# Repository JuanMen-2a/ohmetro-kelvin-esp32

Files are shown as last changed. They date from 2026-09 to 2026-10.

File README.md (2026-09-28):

# Óhmetro Kelvin de 4 Hilos — ESP32 + MQTT + Android

> Trabajo Final — Diseño Electrónico, UIS 2026-II

Instrumento de medición de resistencias de bajo valor (rango: miliohmios) basado en el método Kelvin de 4 hilos. El ESP32 adquiere la señal, la procesa y la transmite vía MQTT a una app Android en tiempo real.

---

## Arquitectura del sistema
Circuito Kelvin → ESP32 → Hotspot celular → Internet → test.mosquitto.org → Internet → App Android

---

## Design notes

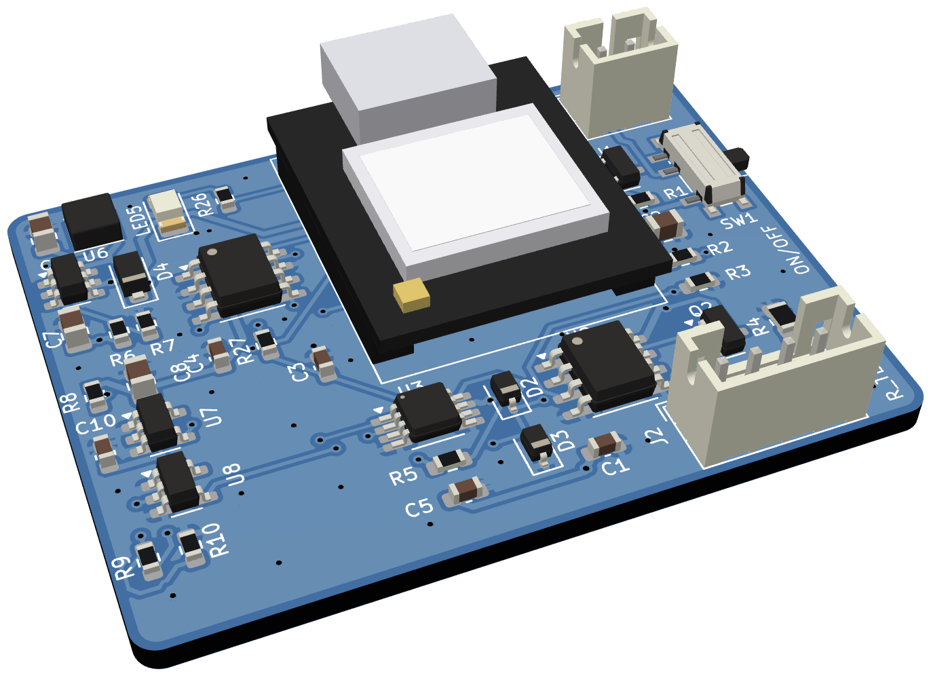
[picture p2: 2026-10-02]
PCB/imagenes/PCB_3D_isometrica.png

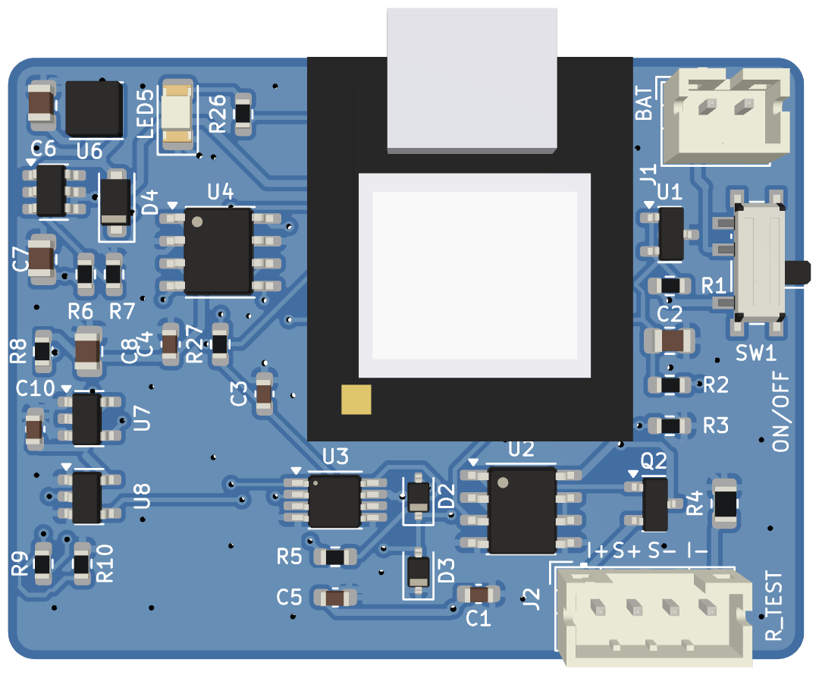
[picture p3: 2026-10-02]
PCB/imagenes/PCB_3D_superior.png

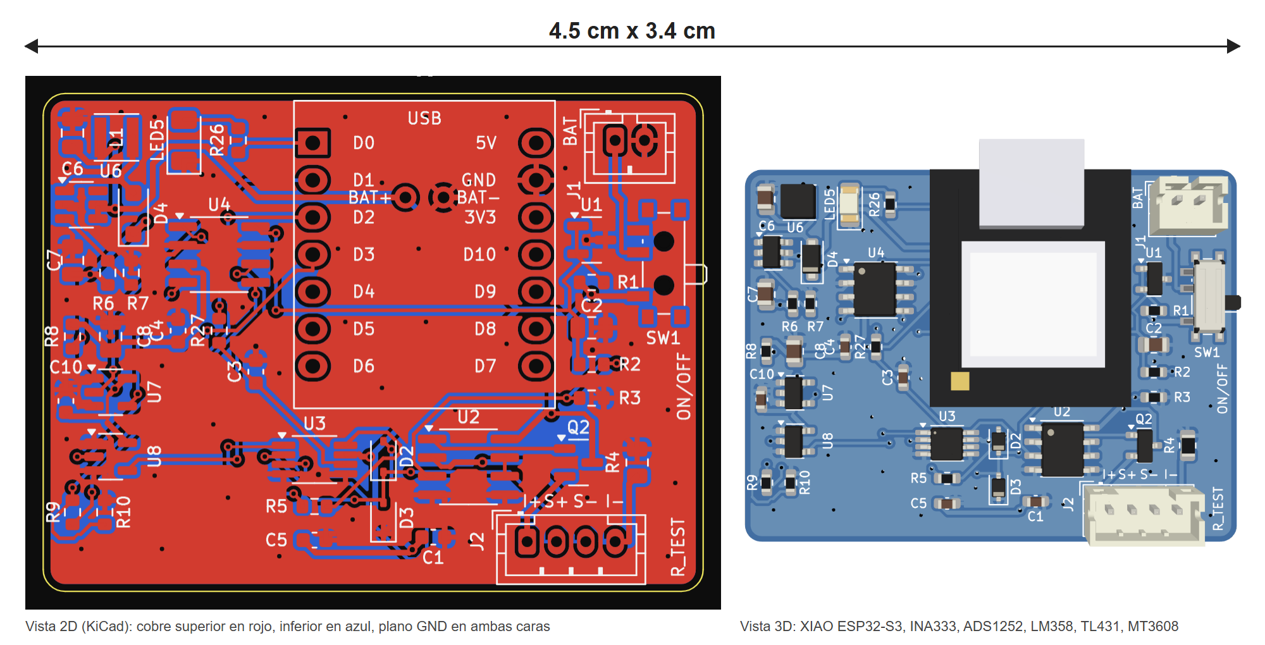
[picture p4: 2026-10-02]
PCB/imagenes/PCB_2D_3D.png

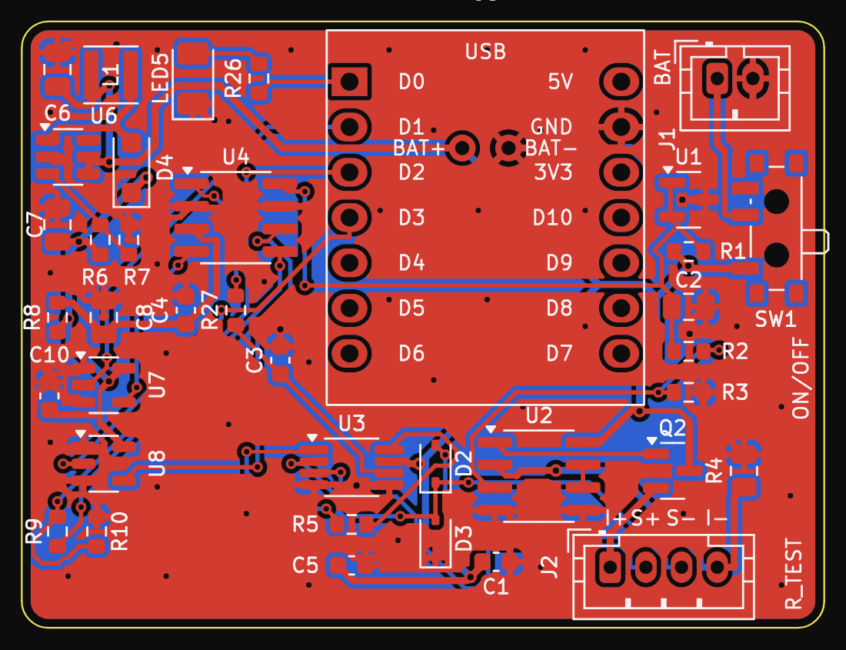
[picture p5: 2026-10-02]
PCB/imagenes/PCB_2D.png

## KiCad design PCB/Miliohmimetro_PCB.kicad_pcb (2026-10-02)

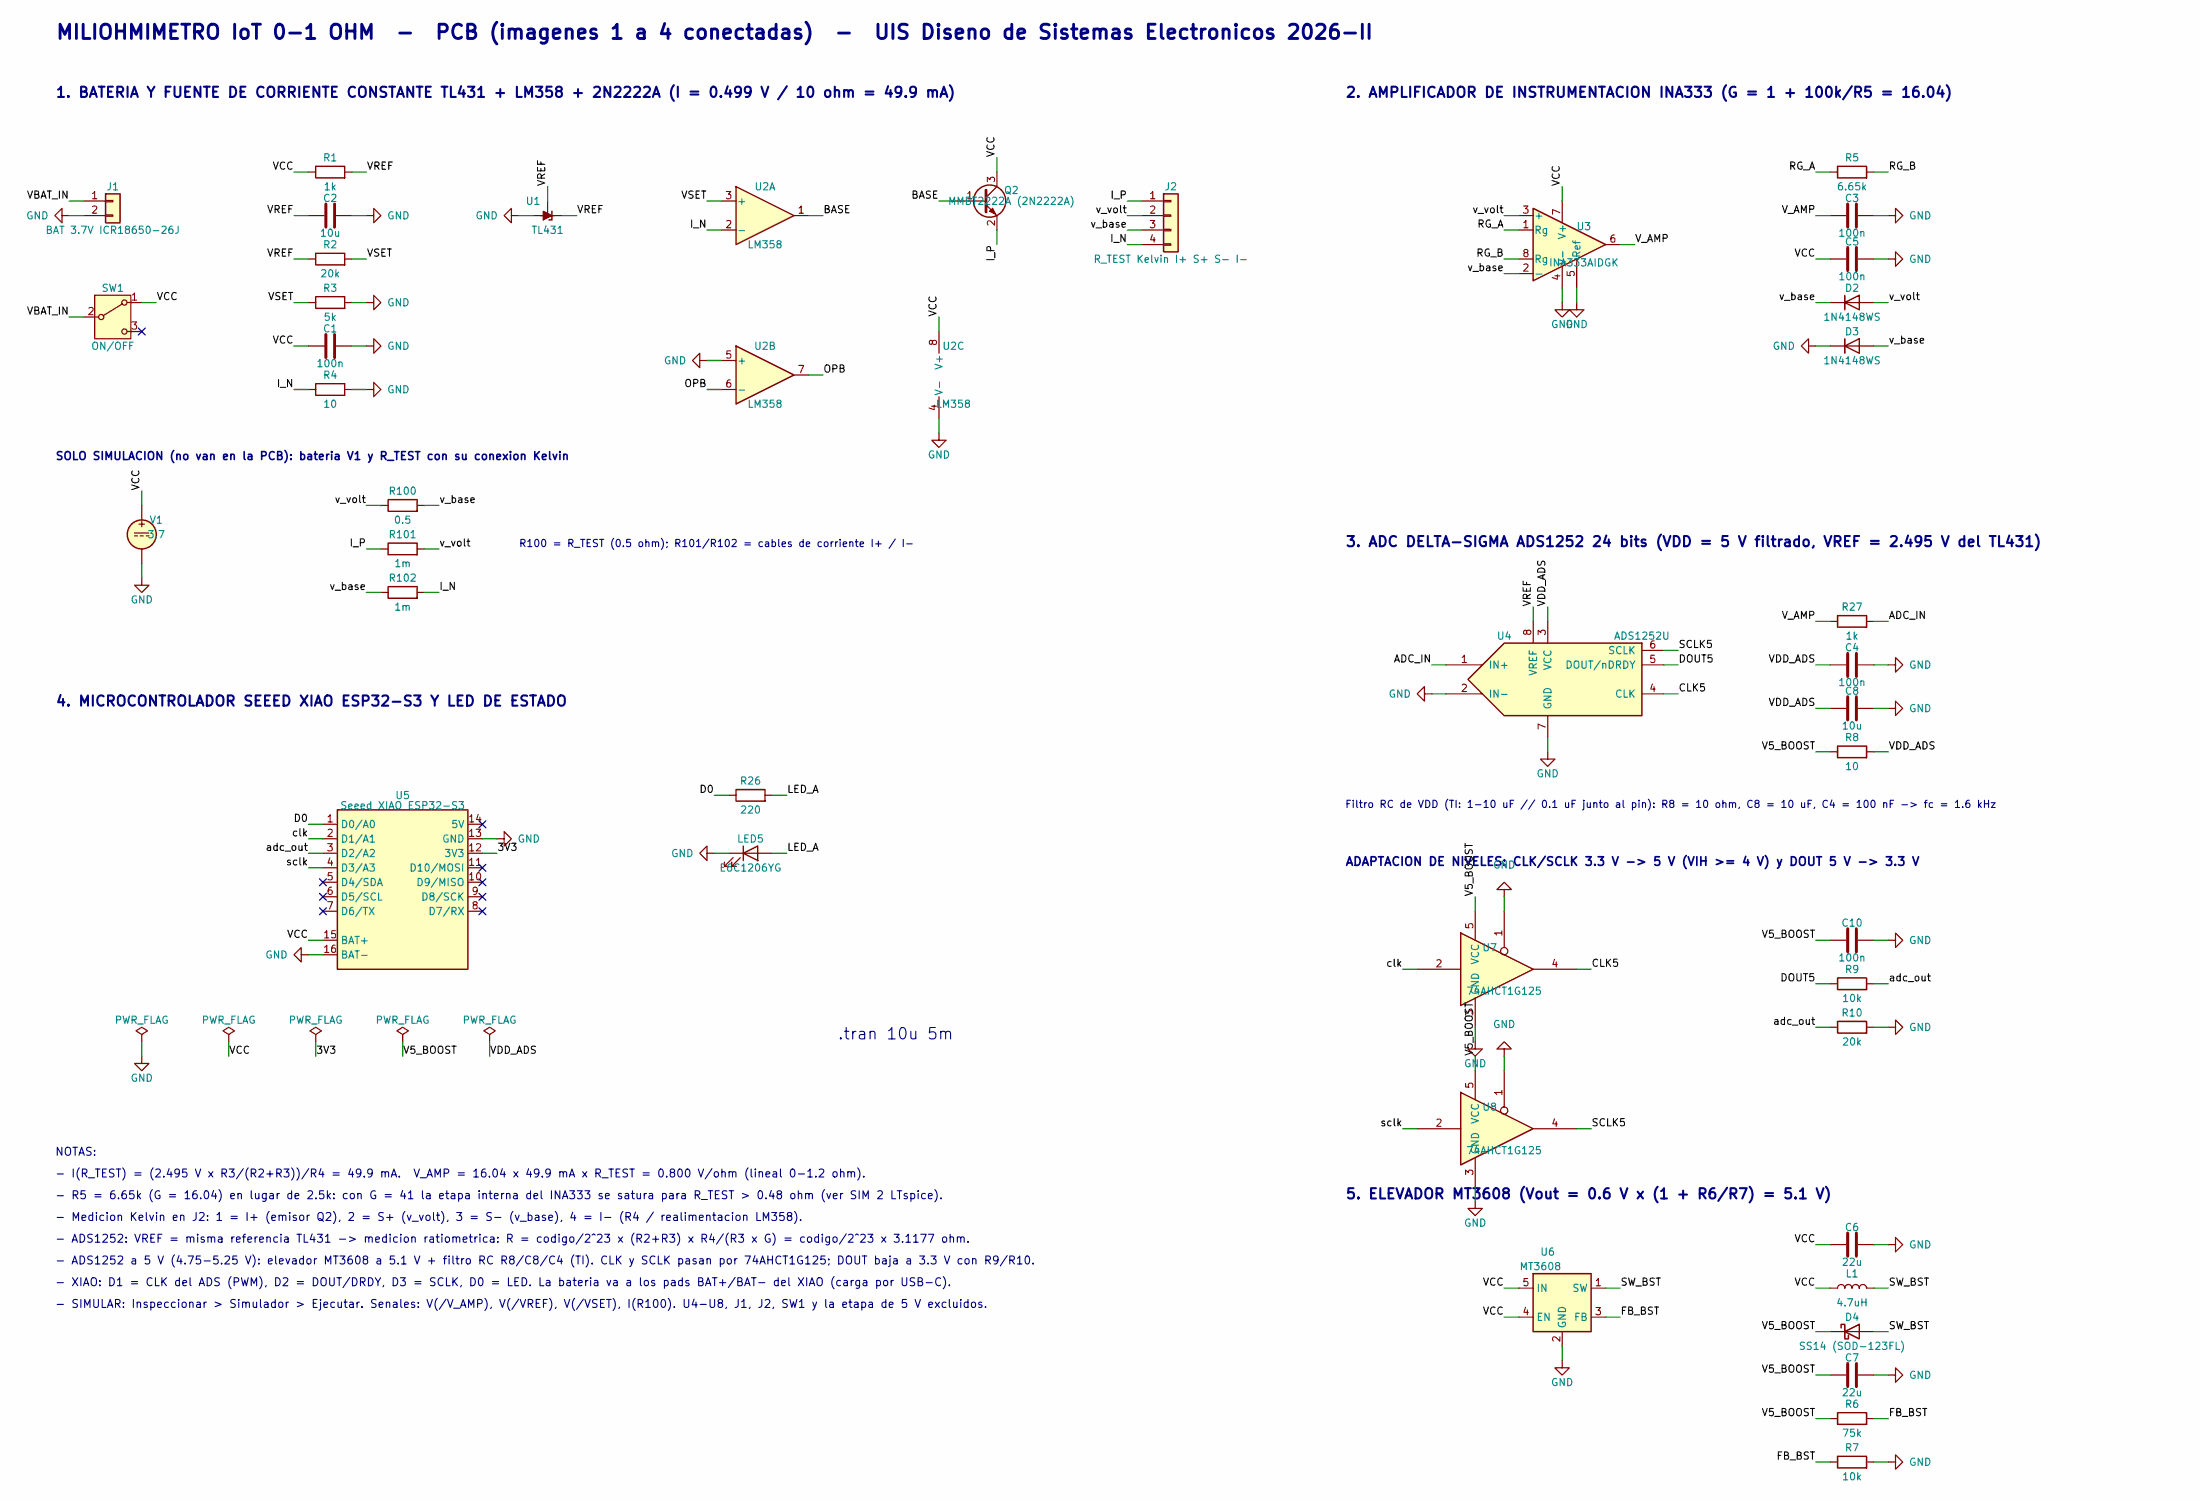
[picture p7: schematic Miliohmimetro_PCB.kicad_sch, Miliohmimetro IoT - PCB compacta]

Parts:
C1, C3, C4, C5, C10: 100n; C_0603_1608Metric
C2, C8: 10u; C_0805_2012Metric
C6, C7: 22u; C_0805_2012Metric
D2, D3: 1N4148WS; D_SOD-323
D4: SS14 (SOD-123FL); D_SOD-123F
J1: BAT 3.7V ICR18650-26J; JST_PH_B2B-PH-K_1x02_P2.00mm_Vertical
J2: R_TEST Kelvin I+ S+ S- I-; JST_PH_B4B-PH-K_1x04_P2.00mm_Vertical
L1: 4.7uH; L_Taiyo-Yuden_NR-30xx
LED5: E6C1206YG; LED_1206_3216Metric
Q2: MMBT2222A (2N2222A); SOT-23
R1, R27: 1k; R_0603_1608Metric
R2, R10: 20k; R_0603_1608Metric
R3: 5k; R_0603_1608Metric
R4: 10; R_0805_2012Metric
R5: 6.65k; R_0603_1608Metric
R6: 75k; R_0603_1608Metric
R7, R9: 10k; R_0603_1608Metric
R8: 10; R_0603_1608Metric
R26: 220; R_0603_1608Metric
R100: 0.5
R101, R102: 1m
SW1: ON/OFF; SW_SPDT_PCM12
U1: TL431; SOT-23
U2: LM358; SOIC-8_3.9x4.9mm_P1.27mm
U3: INA333AIDGK; VSSOP-8_3x3mm_P0.65mm
U4: ADS1252U; SOIC-8_3.9x4.9mm_P1.27mm
U5: Seeed XIAO ESP32-S3; Seeed_XIAO_ESP32S3_THT
U6: MT3608; SOT-23-6
U7, U8: 74AHCT1G125; SOT-23-5
V1: 3.7

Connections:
/3V3: U5.12 (3V3)
/ADC_IN: R27.2, U4.1 (IN+)
/BASE: Q2.1 (B), U2.1
/CLK5: U4.4 (CLK), U7.4
/D0: R26.1, U5.1 (D0/A0)
/DOUT5: R9.1, U4.5 (DOUT/nDRDY)
/FB_BST: R6.2, R7.1, U6.3 (FB)
/I_N: J2.4, R4.1, R102.2, U2.2 (-)
/I_P: J2.1, Q2.2 (E), R101.1
/LED_A: LED5.2 (A), R26.2
/OPB: U2.6 (-), U2.7
/RG_A: R5.1, U3.1 (Rg)
/RG_B: R5.2, U3.8 (Rg)
/SCLK5: U4.6 (SCLK), U8.4
/SW_BST: D4.2 (A), L1.2, U6.1 (SW)
/V5_BOOST: C7.1, C10.1, D4.1 (K), R6.1, R8.1, U7.5 (VCC), U8.5 (VCC)
/VBAT_IN: J1.1, SW1.2 (B)
/VCC: C1.1, C5.1, C6.1, L1.1, Q2.3 (C), R1.1, SW1.1 (A), U2.8 (V+), U3.7 (V+), U5.15 (BAT+), U6.4 (EN), U6.5 (IN), V1.1
/VDD_ADS: C4.1, C8.1, R8.2, U4.3 (VCC)
/VREF: C2.1, R1.2, R2.1, U1.1 (K), U1.2 (REF), U4.8 (VREF)
/VSET: R2.2, R3.1, U2.3 (+)
/V_AMP: C3.1, R27.1, U3.6
/adc_out: R9.2, R10.1, U5.3 (D2/A2)
/clk: U5.2 (D1/A1), U7.2
/sclk: U5.4 (D3/A3), U8.2
/v_base: D2.1 (K), D3.2 (A), J2.3, R100.2, R102.1, U3.2 (-)
/v_volt: D2.2 (A), J2.2, R100.1, R101.2, U3.3 (+)
GND: C1.2, C2.2, C3.2, C4.2, C5.2, C6.2, C7.2, C8.2, C10.2, D3.1 (K), J1.2, LED5.1 (K), R3.2, R4.2, R7.2, R10.2, U1.3 (A), U2.4 (V-), U2.5 (+), U3.4 (V-), U3.5 (Ref), U4.2 (IN-), U4.7 (GND), U5.13 (GND), U5.16 (BAT-), U6.2 (GND), U7.1, U7.3 (GND), U8.1, U8.3 (GND), V1.2

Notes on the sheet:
MILIOHMIMETRO IoT 0-1 OHM - PCB (imagenes 1 a 4 conectadas) - UIS Diseno de Sistemas Electronicos 2026-II
1. BATERIA Y FUENTE DE CORRIENTE CONSTANTE TL431 + LM358 + 2N2222A (I = 0.499 V / 10 ohm = 49.9 mA)
SOLO SIMULACION (no van en la PCB): bateria V1 y R_TEST con su conexion Kelvin
R100 = R_TEST (0.5 ohm); R101/R102 = cables de corriente I+ / I-
2. AMPLIFICADOR DE INSTRUMENTACION INA333 (G = 1 + 100k/R5 = 16.04)
3. ADC DELTA-SIGMA ADS1252 24 bits (VDD = 5 V filtrado, VREF = 2.495 V del TL431)
Filtro RC de VDD (TI: 1-10 uF // 0.1 uF junto al pin): R8 = 10 ohm, C8 = 10 uF, C4 = 100 nF -> fc = 1.6 kHz
ADAPTACION DE NIVELES: CLK/SCLK 3.3 V -> 5 V (VIH >= 4 V) y DOUT 5 V -> 3.3 V
5. ELEVADOR MT3608 (Vout = 0.6 V x (1 + R6/R7) = 5.1 V)
4. MICROCONTROLADOR SEEED XIAO ESP32-S3 Y LED DE ESTADO
.tran 10u 5m
NOTAS:
- I(R_TEST) = (2.495 V x R3/(R2+R3))/R4 = 49.9 mA. V_AMP = 16.04 x 49.9 mA x R_TEST = 0.800 V/ohm (lineal 0-1.2 ohm).
- R5 = 6.65k (G = 16.04) en lugar de 2.5k: con G = 41 la etapa interna del INA333 se satura para R_TEST > 0.48 ohm (ver SIM 2 LTspice).
- Medicion Kelvin en J2: 1 = I+ (emisor Q2), 2 = S+ (v_volt), 3 = S- (v_base), 4 = I- (R4 / realimentacion LM358).
- ADS1252: VREF = misma referencia TL431 -> medicion ratiometrica: R = codigo/2^23 x (R2+R3) x R4/(R3 x G) = codigo/2^23 x 3.1177 ohm.
- ADS1252 a 5 V (4.75-5.25 V): elevador MT3608 a 5.1 V + filtro RC R8/C8/C4 (TI). CLK y SCLK pasan por 74AHCT1G125; DOUT baja a 3.3 V con R9/R10.
- XIAO: D1 = CLK del ADS (PWM), D2 = DOUT/DRDY, D3 = SCLK, D0 = LED. La bateria va a los pads BAT+/BAT- del XIAO (carga por USB-C).
- SIMULAR: Inspeccionar > Simulador > Ejecutar. Senales: V(/V_AMP), V(/VREF), V(/VSET), I(R100). U4-U8, J1, J2, SW1 y la etapa de 5 V excluidos.

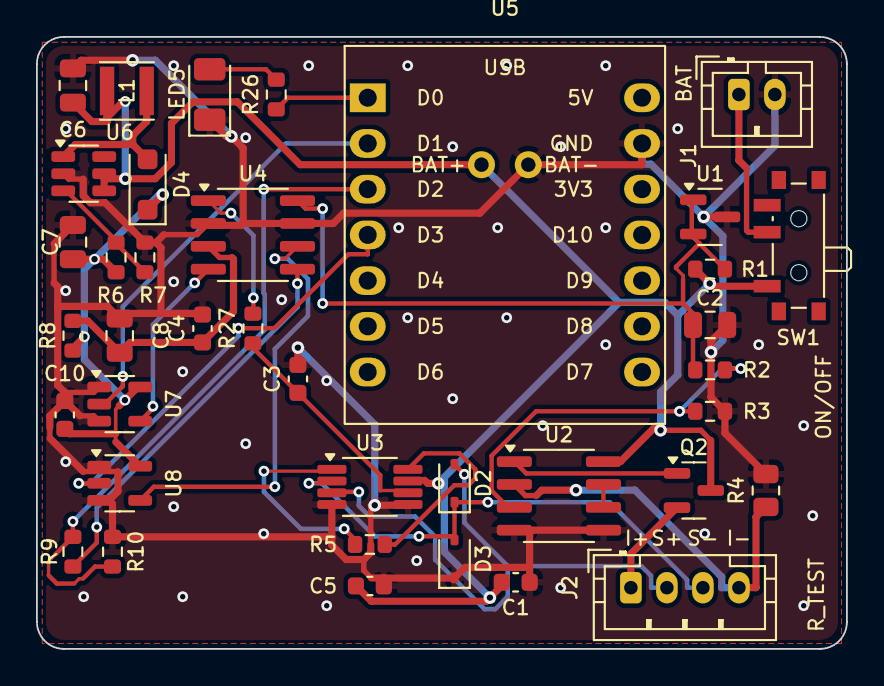
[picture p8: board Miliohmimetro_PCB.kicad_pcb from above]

Board: 2 copper layers, 45.0 x 34.0 mm, 38 parts (0 on the bottom side), 27 nets.

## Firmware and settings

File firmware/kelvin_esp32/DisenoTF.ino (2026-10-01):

#include <WiFi.h>
#include <PubSubClient.h>
#include <ArduinoJson.h>

// ---------- CONFIG WiFi ----------
const char* WIFI_SSID     = "WIFI_SSID";
const char* WIFI_PASSWORD = "WIFI_PASSWORD";

// ---------- CONFIG MQTT ----------
const char* MQTT_BROKER   = "test.mosquitto.org";
const int   MQTT_PORT     = 1883;
const char* TOPIC_MEDICION = "kelvin/medicion/juanuis2026";
const char* TOPIC_COMANDO  = "kelvin/comando/juanuis2026";

// ---------- CONFIG KELVIN ----------
const int   PIN_ADC         = 1;      // GPIO1 - A0 en XIAO ESP32-S3 (ADC1, compatible con WiFi)
const float V_REF           = 3.3;     // Voltaje de referencia del ESP32
const int   ADC_RESOLUTION  = 4095;    // 12 bits
const float I_EXCITACION    = 0.050;   // 50 mA = 0.050 A
const int   N_MUESTRAS      = 20;      // Promedio para reducir ruido

// MODO DE OPERACIÓN:
// true  = usa ADC real (circuito Kelvin conectado)
// false = usa valores simulados (para pruebas sin hardware)
const bool MODO_REAL = false;

WiFiClient   espClient;
PubSubClient mqtt(espClient);

// ---------- ESTADO ----------
bool midiendo = false;
float calibracionOffset = 0.0; // offset en mOhm aplicado a la lectura real
float valorSimulado = 200.0;   // solo se usa cuando MODO_REAL = false
int bateriaPorcentaje = 87;
bool cargando = false;

unsigned long ultimaPublicacion = 0;
const long INTERVALO_MS = 1000;

// ---------- LECTURA ADC REAL (método Kelvin 4 hilos) ----------
float leerResistenciaMOhm() {
  // Promedio de N_MUESTRAS lecturas para reducir ruido del ADC
  long suma = 0;
  for (int i = 0; i < N_MUESTRAS; i++) {
    suma += analogRead(PIN_ADC);
    delayMicroseconds(200);
  }
  float lecturaPromedio = suma / (float)N_MUESTRAS;

  // Conversión ADC → Voltaje
  float voltaje = (lecturaPromedio / ADC_RESOLUTION) * V_REF;

  // Ley de Ohm: R = V / I
  // Con I = 50mA = 0.050A
  // Resultado en Ohm → convertir a mOhm multiplicando por 1000
  float resistenciaOhm  = voltaje / I_EXCITACION;
  float resistenciaMOhm = (resistenciaOhm * 1000.0) + calibracionOffset;

  // Evitar valores negativos por offset o ruido
  if (resistenciaMOhm < 0) resistenciaMOhm = 0;

  return resistenciaMOhm;
}

// ---------- CONECTAR WIFI ----------
void conectarWiFi() {
  Serial.print("Conectando a WiFi: ");
  Serial.println(WIFI_SSID);
  WiFi.mode(WIFI_STA);
  WiFi.begin(WIFI_SSID, WIFI_PASSWORD);

  int intentos = 0;
  while (WiFi.status() != WL_CONNECTED) {
    delay(500);
    Serial.print(".");
    intentos++;
    if (intentos > 40) {
      Serial.println("\nNo se pudo conectar al WiFi. Reiniciando...");
      ESP.restart();
    }
  }
  Serial.println("\nWiFi conectado");
  Serial.print("IP del ESP32: ");
  Serial.println(WiFi.localIP());
}

// ---------- CALLBACK: comandos recibidos ----------
void onMensaje(char* topic, byte* payload, unsigned int length) {
  String mensaje = "";
  for (unsigned int i = 0; i < length; i++) {
    mensaje += (char)payload[i];
  }

  Serial.print("Comando recibido: ");
  Serial.println(mensaje);

  if (mensaje == "iniciar") {
    midiendo = true;
    Serial.println("Medición iniciada");
  } else if (mensaje == "detener") {
    midiendo = false;
    Serial.println("Medición detenida");
  } else if (mensaje == "calibrar") {
    if (MODO_REAL) {
      // Toma la lectura actual como offset para que el resultado sea 0
      float lecturaActual = leerResistenciaMOhm() - calibracionOffset;
      calibracionOffset = -lecturaActual;
      Serial.print("Calibrado. Offset: ");
      Serial.print(calibracionOffset);
      Serial.println(" mOhm");
    } else {
      valorSimulado = 0.0;
      Serial.println("Calibrado (modo simulado)");
    }
  }
}

// ---------- CONECTAR MQTT ----------
void conectarMQTT() {
  while (!mqtt.connected()) {
    Serial.print("Conectando al broker MQTT...");
    String clientId = "ESP32_Kelvin_" + String(random(0xffff), HEX);
    if (mqtt.connect(clientId.c_str())) {
      Serial.println(" conectado");
      mqtt.subscribe(TOPIC_COMANDO);
    } else {
      Serial.print(" falló, rc=");
      Serial.print(mqtt.state());
      Serial.println(" reintentando en 3s");
      delay(3000);
    }
  }
}

// ---------- SETUP ----------
void setup() {
  Serial.begin(115200);
  randomSeed(analogRead(0));
  analogReadResolution(12);

  Serial.println(MODO_REAL ? "Modo: REAL (ADC)" : "Modo: SIMULADO");

  conectarWiFi();

  mqtt.setServer(MQTT_BROKER, MQTT_PORT);
  mqtt.setCallback(onMensaje);
}

// ---------- LOOP ----------
void loop() {
  if (WiFi.status() != WL_CONNECTED) {
    Serial.println("WiFi perdido, reconectando...");
    conectarWiFi();
  }

  if (!mqtt.connected()) {
    conectarMQTT();
  }
  mqtt.loop();

  unsigned long ahora = millis();
  if (ahora - ultimaPublicacion >= INTERVALO_MS) {
    ultimaPublicacion = ahora;

    float valor = 0.0;

    if (midiendo) {
      if (MODO_REAL) {
        // Lectura real del circuito Kelvin
        valor = leerResistenciaMOhm();
      } else {
        // Simulación con ruido aleatorio
        valorSimulado += random(-50, 51) / 10.0;
        if (valorSimulado < 0) valorSimulado = 0;
        valor = valorSimulado;
      }
    }

    StaticJsonDocument<200> doc;
    doc["resistencia_mohm"]   = valor;
    doc["bateria_porcentaje"] = bateriaPorcentaje;
    doc["cargando"]           = cargando;
    doc["midiendo"]           = midiendo;

    String payload;
    serializeJson(doc, payload);

    mqtt.publish(TOPIC_MEDICION, payload.c_str());
    Serial.println("Publicado: " + payload);
  }
}
